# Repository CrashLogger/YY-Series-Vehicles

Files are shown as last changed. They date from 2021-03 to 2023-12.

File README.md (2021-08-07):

# YY Series vehicles

<h2> ENG </h2>
The YY series is a fixed wing single motor 3 or 4 channel radio controlled aircraft series. They follow a classic-for-UAVs double tail boom set up.
As a companion to the YY aircraft, the CS Series is a tank drive series of radio controlled ground vehicles.

Both series operate on the same YY Series controller, which is not compatible with industry standard controllers because of the different value sending method.
Their communication is made via the NRF24l01 2.4GHz chip. They can both be powered by 2S batteries, and in the case of the YY series aircraft, they can also be powered by 3S batteries.

<h2> EUS </h2>
BAL proiekturako eginiko kodea. YY serieko hego finkodun, motore bakardun, 3 edo 4 kanaleko radioz kontrolaturiko hegazkin seriea da. Isatz bikoizdun itxurakoa.
YY serie hegazkinarekin batera, CS serieko autoa, tanke erara gidatutako lur ibilgailuak ere badaude.

Bi serieek kontrol sistema berbera erabiltzen dute, industriako estandarrekin konpatibleak ez direnak.
NRF24L01 txipdun moduluen bitartez komunikatzen dira, kanal bakar baten bidez. Biek 2S litio bateriekin erabili daitezke, baina YY seriearen kasuan 3S bateriek ere erabili daitezke.
NRF24L01 txipdun moduluen bitartez komunikatzen dira, kanal bakar baten bidez. Biek 2S litio bateriekin erabili daitezke, baina YY seriearen kasuan 3S bateriak ere erabili daitezke.

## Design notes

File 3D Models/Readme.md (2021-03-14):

About PCB.blend

The V1 version had the radio and joystick breakout board cables soldered straight into the Arduino Nano's pins.
This has been changed, and soon to be updated to use the pins on the board for ease of use.

About Plane Inaaccurate.FCStd

This is a very rough version of the YY Series aircraft, more akin to the YY-120 MKI than to any of the posterior modular more rigid variations of the series.
The fuselage has also been extended for easier balancing, and this model is to be updated soon.

About Airfoils Printable_0.FCStd

These are the ribs to mount on the 12mm or 13mm wide posts that make up the frame of the YY series aircraft.
They're an elongated Clark Y Airfoil which becomes a bit longer depending on how tightly it fits.

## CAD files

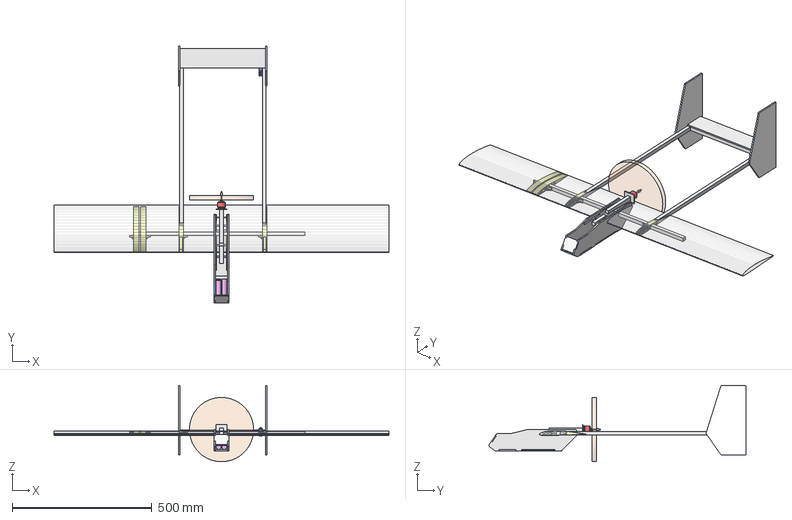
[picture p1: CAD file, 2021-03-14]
3D Models/Plane_Inaccurate.FCStd
1200.0 x 921.8 x 273.4 mm
Rotor_main
Stator
Rotor_shaft
AlumMount
MountBolt
PropellerDisk
TailCone
Connect008 (Mirror #7)
Connect012
Wing
Frame_Full
Vert_Stabiliser_R
Vert_Stabiliser_L
Horiz_Stabiliser
Servo
ServoTip
Fuselage_B_F

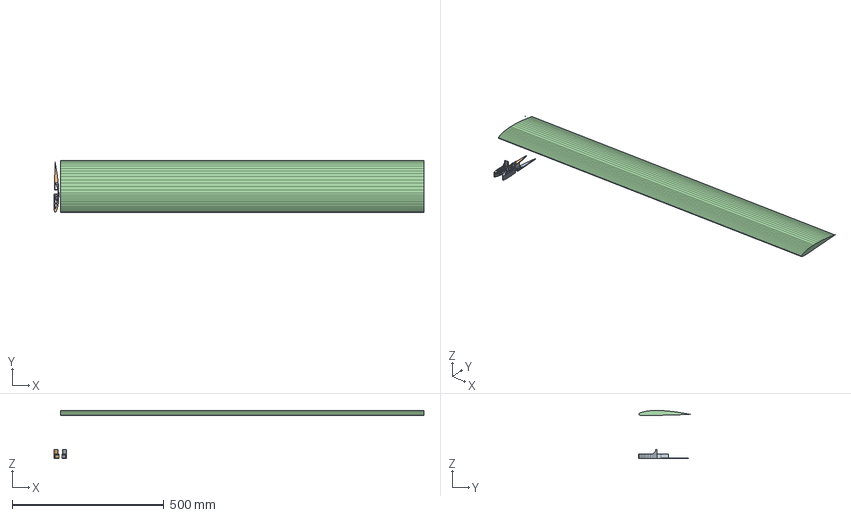
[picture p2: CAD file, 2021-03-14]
3D Models/AirfoilsPrintable_0.FCStd
1220.8 x 170.0 x 163.0 mm
Wire

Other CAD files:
3D Models/PCB_V1.blend

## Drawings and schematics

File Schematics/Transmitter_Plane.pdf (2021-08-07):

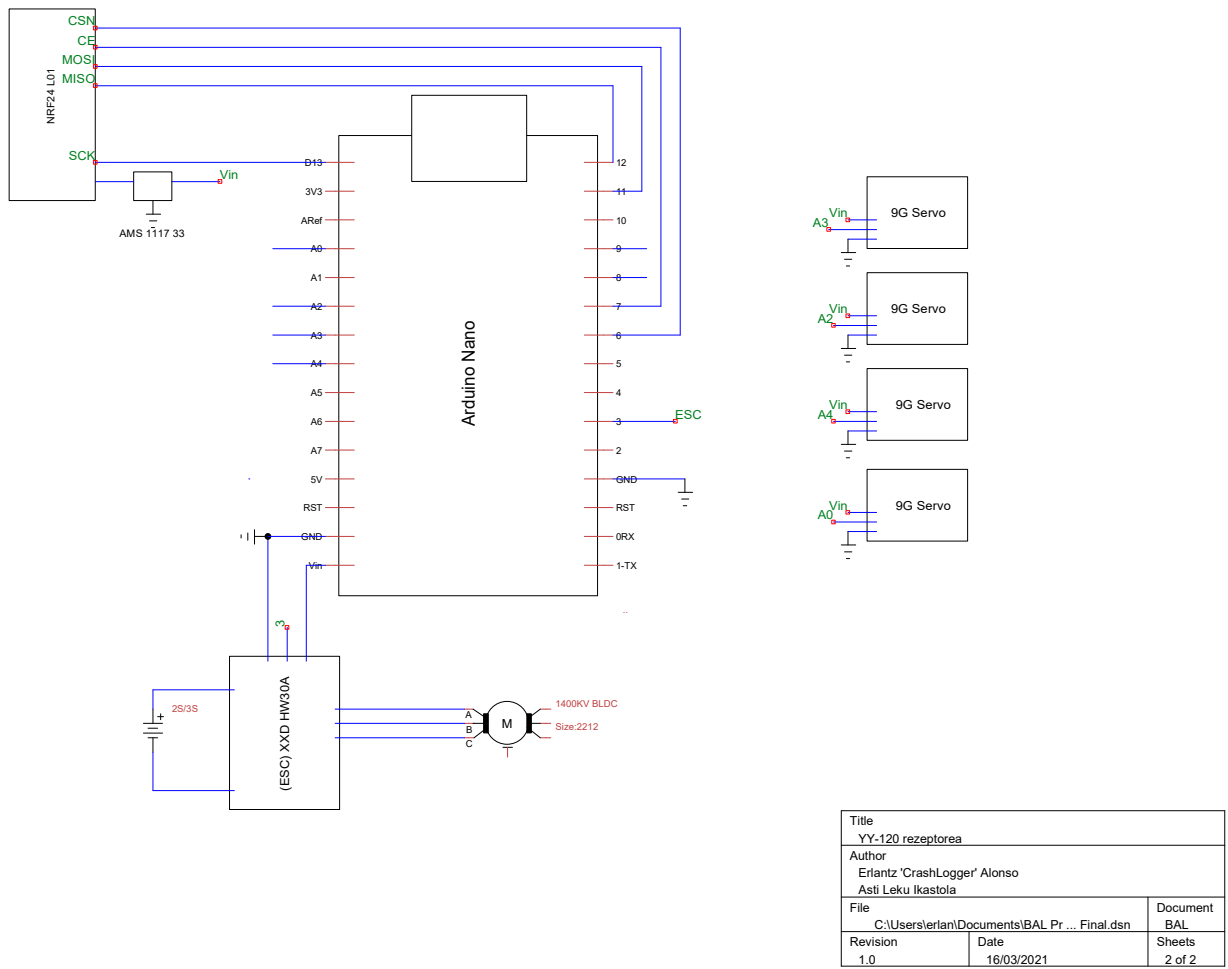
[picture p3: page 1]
ARef; RST; GND; Vin; AMS 1117 33 NRF24 L01; Arduino Nano; ESC; 1400KV BLDC; Size:2212; 9G Servo; SCK; MISO; MOSI; CSN

A0 (ESC⁾ XXD HW³⁰A

Title
YY-120 rezeptorea
Author
Erlantz 'CrashLogger' Alonso
Asti Leku Ikastola

File C:\Users\erlan\Documents\BAL Pr ... Final.dsn | Document BAL

Revision 1.0 | Date 16/03/2021 | Sheets 2 of 2

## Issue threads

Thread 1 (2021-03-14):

PS2 joystick inaccuracy

CrashLogger, 2021-03-14:
As I mentioned in some commit details, this is a known issue for some reason, at least when using XXD HW30A brushless motor speed controllers.

These controllers don't seem to get the full PWM signal from the Arduino for some reason, which makes them go full throttle as soon as the joystick leaves the soft dead zone. (They don't have a hard dead zone so I had to code one in myself)

Using a regular 10KΩ potentiometer or a higher quality joystick, however, yields much more precise result for all control surfaces and the motor itself.
Another alternative could be to use a separate throttle potentiometer, but in my current set-up I won't be able to fit that.

One of the things planned is to make the motor run on the speed determined by the variation of the potentiometer instead of it's absolute position, but I'm not sure how much that will hurt performance of the poor microcontroller.

CrashLogger, 2021-03-15:
To aliviate this in the car, the motors will always snap to full power upon detecting an angle of 30º past the center of the deadzone, not to have unexpectedly uneven torque on each side.
The plane will automatically hit whatever it thinks the joystick is telling it to hit still.

CrashLogger, 2021-08-08:
Since Precision Update 2, the car motors are being tuned to work with PS2 Joysticks a little better and have some control over speed.

CrashLogger, 2021-08-10:
The inaccuracies in the main motor seem to come from the motor driver, I'll be looking into tuning it further ASAP.

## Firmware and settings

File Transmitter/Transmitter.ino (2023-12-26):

/*
 * 
 * An NRF24L01 based RC transmitter for RC vehicles
 * An NRF24L01 PA/LNA module is used on this side
 * Designed to run a BLDC motor and 3 servos in it's original form (for rudder and elevator controls)
 * 
 * First created for the YY Series fixed wing aircraft
 * 
 * Erlantz 'CrashLogger' Alonso, 2021
 * 
*/
#include <SPI.h>
#include "printf.h"
#include "RF24.h"

int joyX1 = A3;
int joyY1 = A4;
int joyX = A0;
int joyY = A1;
int joySw1 = 9;
int joySw = 8;

uint8_t turn; 

// int redLED = 5;
// int blueLED = 3;
// int greenLED = 4; 

//Creates object
RF24 radio(6, 7); //CE, CSN

struct Package{
  uint8_t control;
  uint8_t val;
};

Package data;

uint8_t address[][6] = {"gyroc", "gyroc"};

bool radioNumber = 0; // 0 uses address[0] to transmit, 1 uses address[1] to transmit

void setup() {

  Serial.begin(115200);

  // data.thrust = 0;
  // data.rudder = 0;
  // data.elevator = 0;
  // data.aileron = 0;
  // data.brake = false;

  data.control = 0;
  data.val = 0;
  
  pinMode(joySw, INPUT_PULLUP);
  pinMode(joySw1, INPUT_PULLUP);
  pinMode(joyX, INPUT);
  pinMode(joyY, INPUT);
  pinMode(joyX1, INPUT);
  pinMode(joyY1, INPUT);
  // pinMode(blueLED, OUTPUT);
  // pinMode(greenLED, OUTPUT);
  // pinMode(redLED, OUTPUT);

  if (!radio.begin()) {
    while (1) {} //Holds for checking
    Serial.println("AA");
    RadioFail();
  }
  Serial.println("Connected");
  radio.setChannel(60);

  radioNumber = 0;
  radio.setPALevel(RF24_PA_HIGH);  // RF24_PA_MAX
  //OPTIONS ARE: "MIN" "LOW" "HIGH" "MAX"
  
  //Sets size of payload for reliability
   Serial.print(F("SIZE"));
   Serial.println(sizeof(Package));
  radio.setPayloadSize(sizeof(Package));
  radio.setAutoAck(false);

  // set the TX address of the RX node into the TX pipe
  radio.openWritingPipe(address[radioNumber]);
  
  //Sets the RX address of the TX node into an RX pipe for acknowledgements
  radio.openReadingPipe(1, address[radioNumber + 1]);
  //Puts radio in TX mode
  radio.stopListening();

  // digitalWrite(greenLED, HIGH);
  // digitalWrite(blueLED, HIGH);
  // digitalWrite(redLED, HIGH);
  // delay(50);
  // digitalWrite(redLED, LOW);
  // delay(50);
  // digitalWrite(redLED, HIGH);
  // delay(50);
  // digitalWrite(redLED, LOW);
  // delay(100);
  // digitalWrite(blueLED, LOW);

}

void RadioFail(){
  // digitalWrite(redLED, HIGH);
  // delay(100);
  // digitalWrite(redLED, LOW);
  // delay(250);
  // digitalWrite(redLED, HIGH);
  // delay(100);
  // digitalWrite(redLED, LOW);
  // delay(500);
}

void loop() {
    unsigned long start_timer = micros();
    bool report = radio.write(&data, sizeof(Package));
    unsigned long end_timer = micros();

      switch(turn){
        case(0):
          Serial.println("Sending 0");
          data.control = 0b00000000;
          data.val = analogRead(joyX);
          turn++;
          break;
        case(1):
          Serial.println("Sending 1");
          data.control = 0b00000001;
          data.val = analogRead(joyY);
          turn++;
          break;
        case(2):
          Serial.println("Sending 255");
          data.control = 0b11111111;
          data.val = analogRead(joyX1);
          turn++;
          break;
        default:
          turn = 0;
          break;
      }

      // data.thrust = map (analogRead(joyX), 0, 1023, 1023, 0);
      // data.elevator = map (analogRead(joyX1), 0, 1023, 1023, 0);
      // data.rudder = analogRead(joyY);
      // data.aileron = analogRead(joyY1);
      // data.brake = !digitalRead(joySw);
      // data.buzzer = !digitalRead(joySw1);


    // if (report) {
    //   digitalWrite(greenLED, HIGH);
    //   if ((start_timer - end_timer) > 500000){
    //     digitalWrite(blueLED, HIGH);
    //   }
    //   else{
    //     digitalWrite(blueLED, LOW);
    //   }
    // } else {
    //    digitalWrite(greenLED, LOW);
    //    RadioFail();
    // }
    //delay(10);
}

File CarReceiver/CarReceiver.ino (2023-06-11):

   /*
 * 
 * An NRF24L01 based RC receiever for L298N based 4 wheel or two wheel drive vehciles with tank steering
 * A standard short pcb laid antenna NRF24L01 is used on this side
 * Designed to run a two pairs of DC motors for tank steering
 * 
 * First created for the CS-25 "Car System 25cm" 4WD vehicle
 * 
 * Erlantz 'CrashLogger' Alonso, 2021
 * 
*/

//To go forward       Left side: 6H 9L                Right side: 4H 5L
//To go backward      Left side: 6L 9H                Right side: 4L 5H

#include <SPI.h>
#include "printf.h"
#include "RF24.h"

struct Package{
  int thrust;
  int rudder;
  int elevator;
  int aileron;
  bool brake;
  bool buzzer;
};
Package data;

//A3 is the reversing light
//A2 is the left indicator
//A1 is the right indicator
//A0 are the braking lights

RF24 radio(7, 8); // using pin 7 for the CE pin, and pin 8 for the CSN pin

uint8_t address[][6] = {"000FA", "000FF"};    //REC, ACK
bool radioNumber = 1; //Receiver will use pipe [1] to transmit acknowledgements

int PowerR = 0;
int PowerL = 0;

int Margin = 64;

int turningRight = 0;
int turningLeft = 0;

unsigned long blinkPeriod = 500;
unsigned long lastMark = 0;
bool blinkerState = false;
unsigned long currentTime;

void setup() {

  // Initialise the SPI bus transciever
  if (!radio.begin()) {
    ////Serial.println(F("radio hardware is not responding!!"));
    while (1) {} // Hold in infinite loop if it can't connect to the controller
  }

  //radio.enableAckPayload();

  pinMode(A0, OUTPUT);
  pinMode(A1, OUTPUT);
  pinMode(A2, OUTPUT);
  pinMode(A3, OUTPUT);

  radioNumber = 1;
  radio.setPALevel(RF24_PA_HIGH);  // RF24_PA_MAX is default.
  //Optimise sending time by setting the maximum to the variables size
  radio.setPayloadSize(sizeof(data));
  
  //Sets the pipes in the receiver order, opposite to the transmitter order.
  radio.openWritingPipe(address[radioNumber]);
  radio.openReadingPipe(1, address[!radioNumber]);
  radio.startListening();
}

void loop() {
  
  currentTime = millis();
  checkBlinkers();
  blinkers();
  brakeLights();
  reversingLight();

    uint8_t pipe;
    if (radio.available(&pipe)) {                 // Check if there's a package waiting
      uint8_t bytes = radio.getPayloadSize();     // Read the package size
      radio.read(&data, bytes);                   // Read the package
   }
  Power();
}

 void checkBlinkers(){


  if(currentTime - lastMark >= blinkPeriod){
    lastMark = millis();
    if(blinkerState == false){
      blinkerState = true;
    }
    else{
      blinkerState = false;
    }
  }
}

void Power(){
  Left();
  Right();
  if (PowerL>255){
    PowerL = 255;
  }

  if (PowerR > 255){
    PowerR = 255;
  }

  analogWrite(3, PowerR);
  analogWrite(10, PowerL);
}

void Left(){
  if (data.thrust>((1024/2)+Margin)){
    digitalWrite(6, HIGH);
    digitalWrite(9, LOW);
    PowerL = map(data.thrust, (1024/2)+Margin, 1024, 64, 255);
    turningLeft = -1;
  }
  else if (data.thrust<((1024/2)-Margin)){
    digitalWrite(6, LOW);
    digitalWrite(9, HIGH);
    PowerL = map(data.thrust, (1024/2)-Margin, 24, 64, 255);
    turningLeft = 1;
  }
  else{
    digitalWrite(6, LOW);
    digitalWrite(9, LOW);
    PowerL = 0;
    turningLeft = 0;
  }
}

void Right(){
  if (data.elevator>((1024/2)+Margin)){
    digitalWrite(5, HIGH);
    digitalWrite(4, LOW);
    PowerR = map(data.elevator, (1024/2)+Margin, 1024, 64, 255);
    turningRight = 1;
  }
  else if (data.elevator<((1024/2)-Margin)){
    digitalWrite(5, LOW);
    digitalWrite(4, HIGH);
    PowerR = map(data.elevator, (1024/2)-Margin, 24, 64, 255);
    turningRight = -1;
  }
  else{
    digitalWrite(5, LOW);
    digitalWrite(4, LOW);
    PowerR = 0;
    turningRight = 0;
  }
  
}

void brakeLights(){
  if(PowerL < 64 && PowerR < 64){
    digitalWrite(A0, HIGH);
  }
  else{
    digitalWrite(A0, LOW);
  }
}

void reversingLight(){
    if(turningRight == -1 && turningLeft == -1){
    digitalWrite(A3, HIGH);
  }
  else{
    digitalWrite(A3, LOW);
  }
}

void blinkers(){

  if((turningRight > 0 && turningLeft <= 0) || (turningLeft < 0 && turningRight >= 0)){
    digitalWrite(A2, blinkerState);
  }
  else if((turningLeft > 0 && turningRight <= 0) || (turningRight < 0 && turningLeft >= 0)){
    digitalWrite(A1, blinkerState);
  }
  else{
    digitalWrite(A1, LOW);
    digitalWrite(A2, LOW);
  }

}

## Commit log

2021-03-13 First version
    Added basic controls and information about the vehicle series, created for universal control of any and all ground, air and water surface vehicles via the 2.4GHz ISM band using the commonplace NRF24l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
    YY Series aircraft (YY-120 MKII)
    CS Series tank drive ground vehicle (CS-25 MKI)
    YY Series controller MKI
2021-03-14 Precision update 1
    Every transceiver now uses a 10 bit integer (straight from the ADC) for communication.
    This allows for much higher precision when using finely tuned joysticks or potentiometers, but regular PS2 style joysticks on breakout boards will barely make a difference, they will pretty much stil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
    I'm looking into a different way to do this, where even the worst joysticks will make a difference, but the XXD HW30A ESC (or at least mine) seems to be really poorly tuned and can't be tuned all tha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
    [AirfoilsPrintable_0.FCStd, PCB_V1.blend, Plane_Inaccurate.FCStd]
2021-06-18 Revert "Create Schematics.pdf"
    This reverts commit 44b953eb4d4124ab6881a0121457208930ae65bd.
2021-08-07 Precision update 2
    A CS-25 class ground vehicle now has a bit better control over it's speed, but this will vary depending on how expensive you went / lucky you were with your joysticks and the amount of interference these suffer from, so if it's painfully unreliable, wrap your joystick and / or radio signal wires in grounded aluminium foil or tread them around a ground wire individually. It's a bit of an annoying change to make but it may just help out massively.
    Other side changes:
    +Minimally improved comments
    +Fixed the delay after moving the elevator on the plane, a stray Serial.print line was left uncommented (Rookie mistake, my bad).
    +Added schematics for the exact circuits I used (CS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
    [CarReceiver.ino, PlaneReceiver.ino, Transmitter.ino]
2022-08-10 Minor changes
    It will now have false positive throttle issues at times but it works better with the current revision.
    I do plan to get rid of this half assed logic soon though
    [CarReceiver.ino]
2023-06-11 Fixed rotation direction
    I've made a board for this, and I accidentally changed pins 4 and 5 in hardware. So of course we fix that in software.
    [CarReceiver.ino]
2023-06-11 Implemented lights
    -Indicators
    -Brake lights
    -Reversing light(s)
    They're all automatically turned on/off.
    There's a comment explaining how this works, but just in case:
    A3 is the reversing light
    A2 is the left indicator
    A1 is the right indicator
    A0 are the braking lights
    [CarReceiver.ino]
